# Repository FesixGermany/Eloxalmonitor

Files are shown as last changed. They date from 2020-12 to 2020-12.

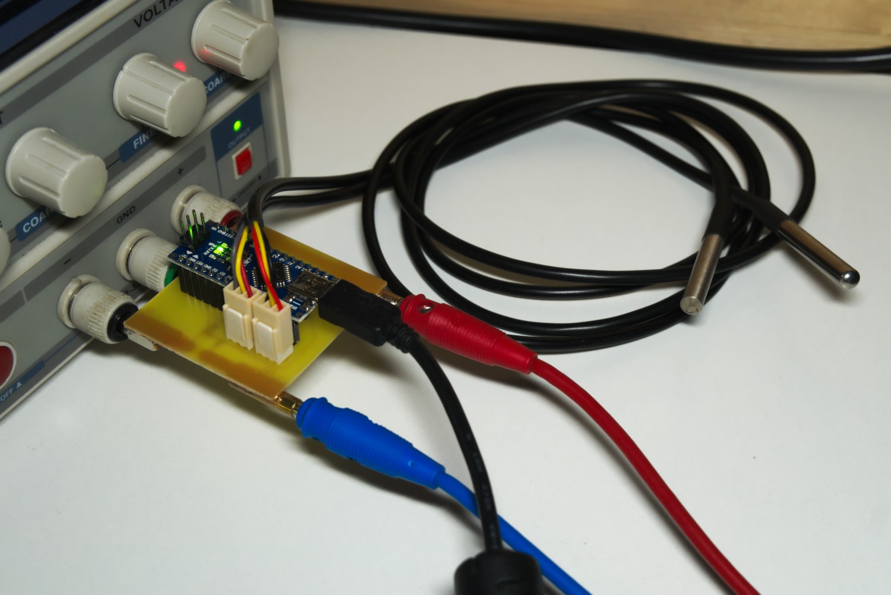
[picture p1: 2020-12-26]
documentation/overview.jpg

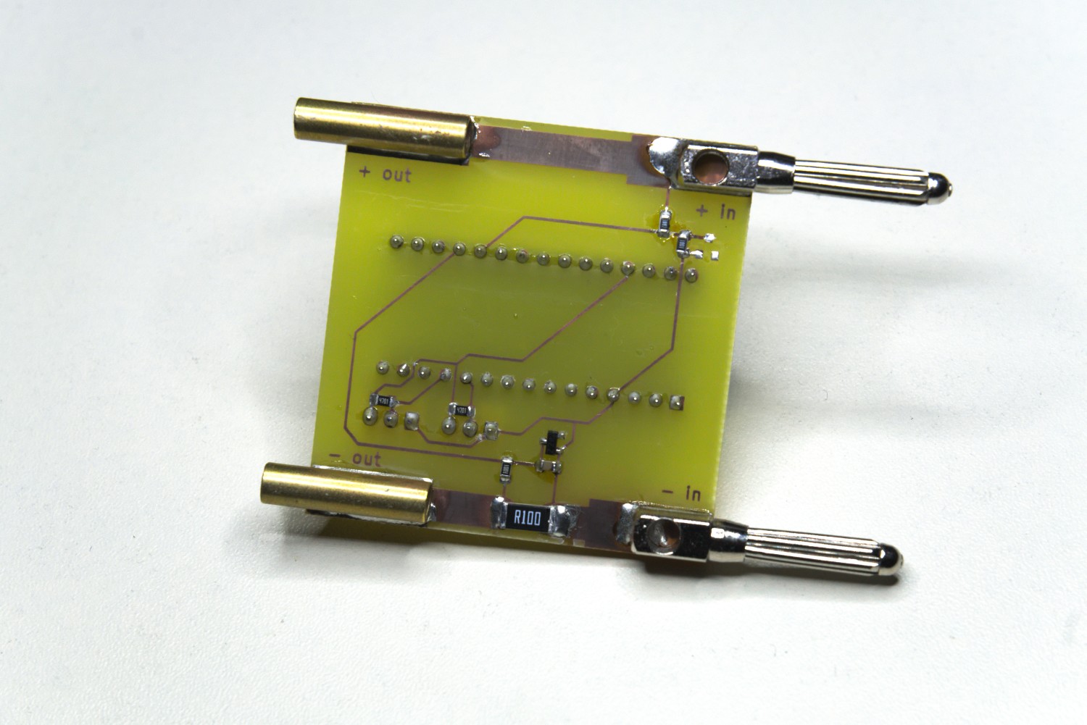
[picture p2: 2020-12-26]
documentation/PCB back.jpg

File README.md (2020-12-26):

# Eloxalmonitor  

This project started some years back when I started anodizing some aluminium at home.  
The temperature of the bath is very critical, when it gets too high the developed oxide pores start to destroy themselfes.  
That's why I wanted to read at least the temperature, voltage and current would be nice to know too.  

My friend Sven Mueller (who sadly passed away in 2018 just shy of 24 years old) wrote parts of the code, mainly the functions for onewire communication and decoding of the temperature back in 2017.  
I forgot about the project but now got into it again and finished it as good as I could by myself.  

## Circuit  

The brain is an Arduino Nano clone, convenient to use for serial communication with UART to USB converter on board.  
The main PCB plugs directly into my lab power supply, voltage gets read via voltage divider up to 30V DC, current is read via a 0R1 shunt resistor.  
Temperature of two basins can be read with two DS18B20 sensors who can be bought with cable attached and stainless steel cap.  

## Firmware 

The firmware for the ATmega 328P controller on the Nano is written in ATMEL Studio, not in Arduino IDE, therefore the controller was programmed with the .hex file which was compiled from ATMEL Studio via a AVR ISP programmer.
As far as I know it is possible to send the compiled .hex to an Arduino over USB with the bootloader installed and the program avrdude but didn't try that.  
**Important to note:** If compiling code yourself it is neccessary to add **libprintf_flt** to linker libraries and **use vprintf** library is set!

## Python GUI  

Script draws four graphs in realtime and stores them in a CSV file.  

Tested with/dependencies:  
python 2.7  
pyserial 3.5  
matplotlib 2.2.5  
numpy 1.16.0  

This is the first script I wrote in python, took some time to figure out how, I'm sure there are better ways but it works for me.

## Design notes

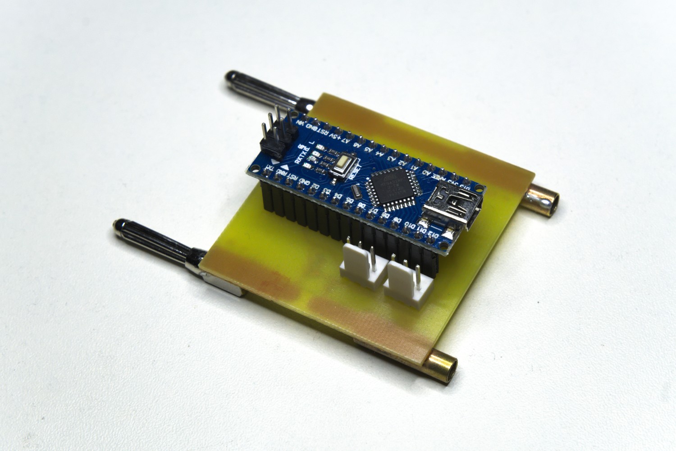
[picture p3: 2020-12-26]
documentation/PCB front.jpg

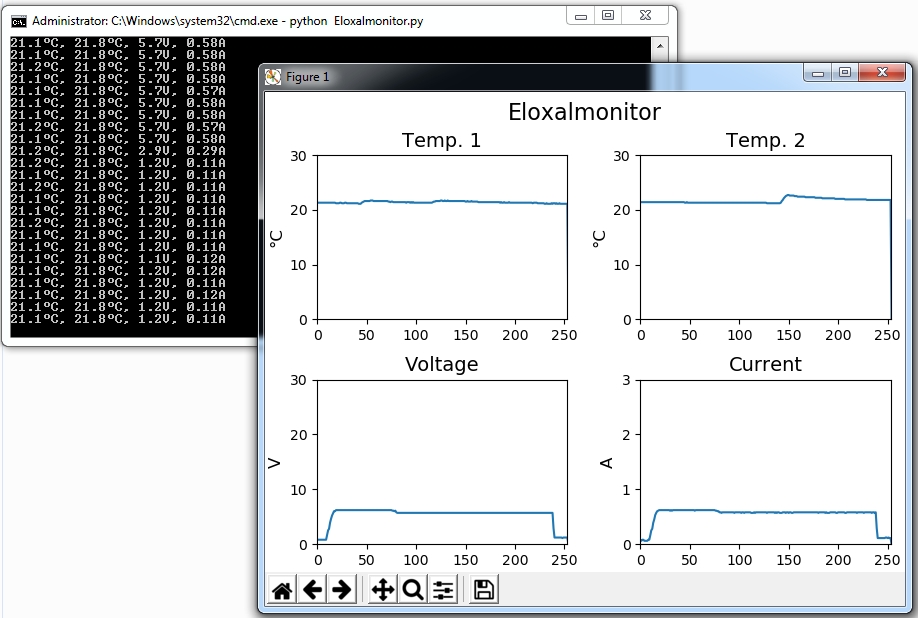
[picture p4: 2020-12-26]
documentation/python.jpg

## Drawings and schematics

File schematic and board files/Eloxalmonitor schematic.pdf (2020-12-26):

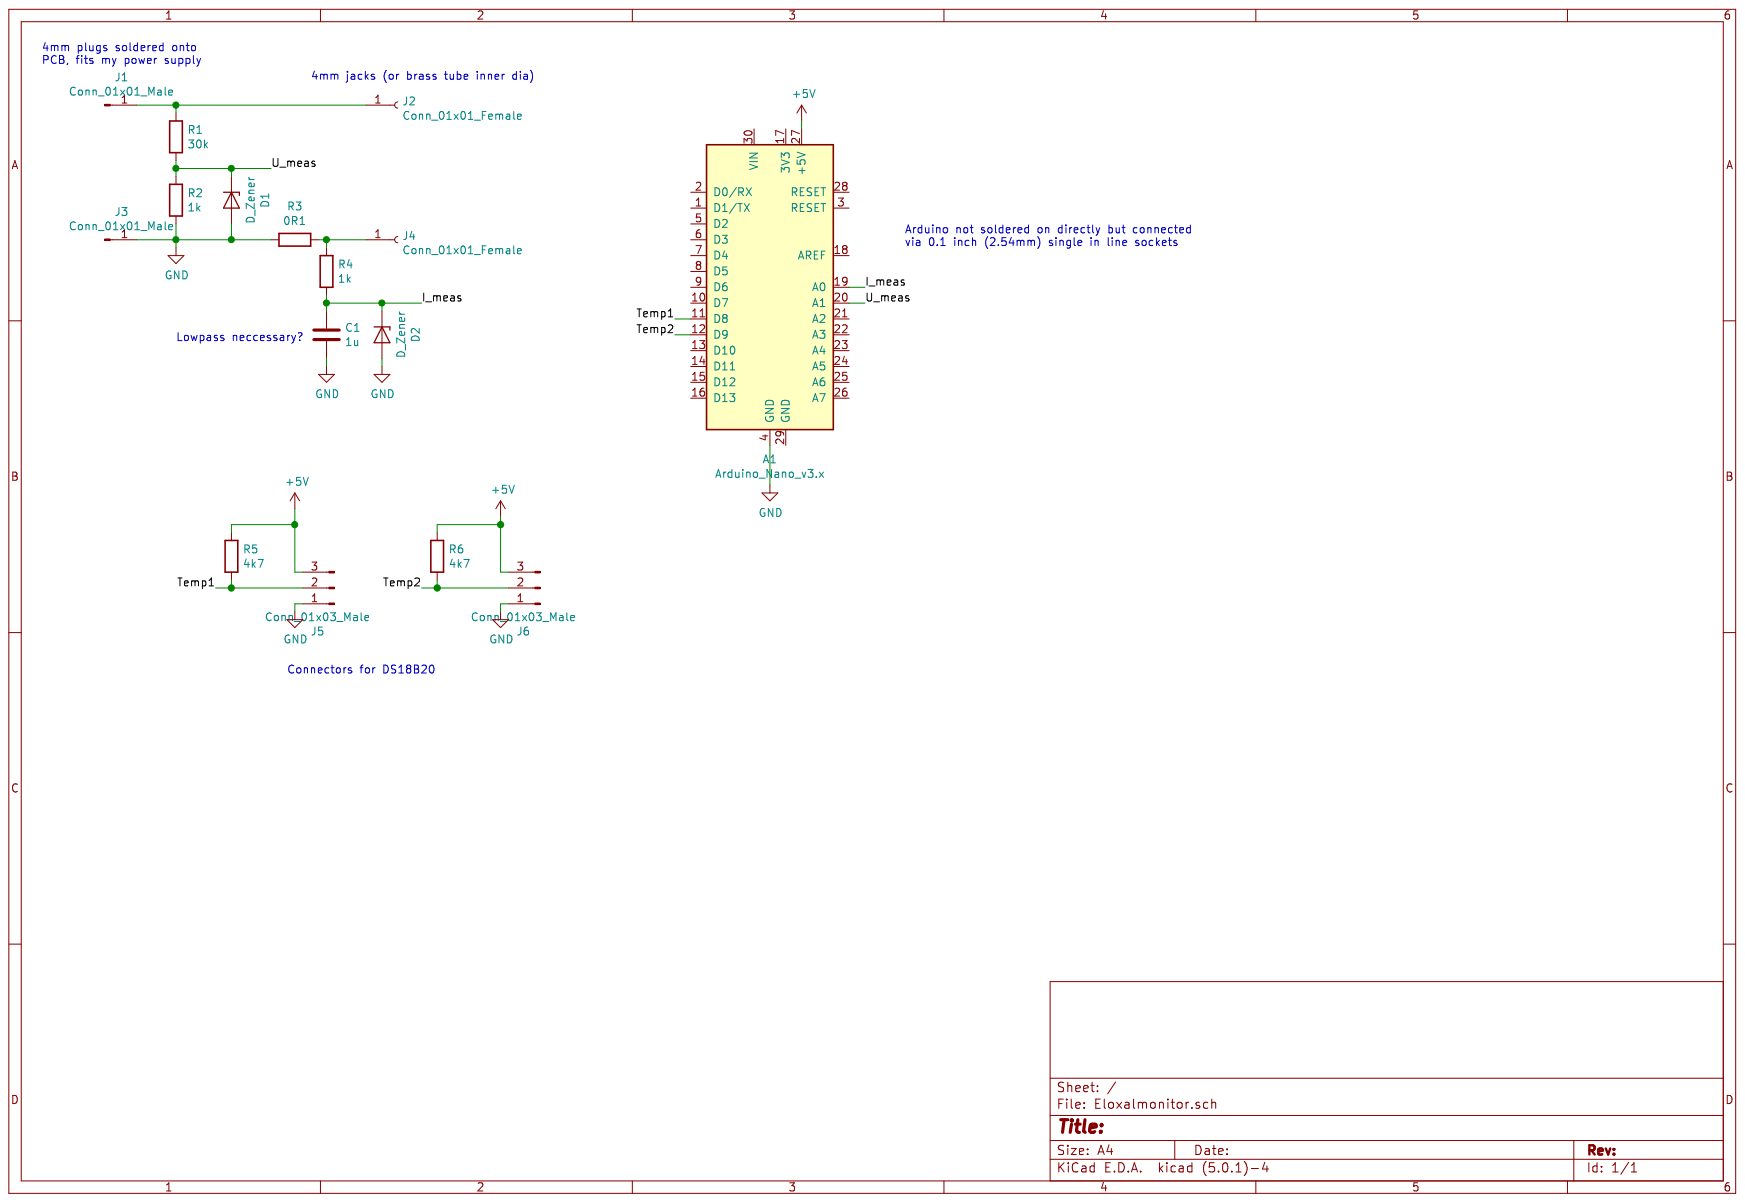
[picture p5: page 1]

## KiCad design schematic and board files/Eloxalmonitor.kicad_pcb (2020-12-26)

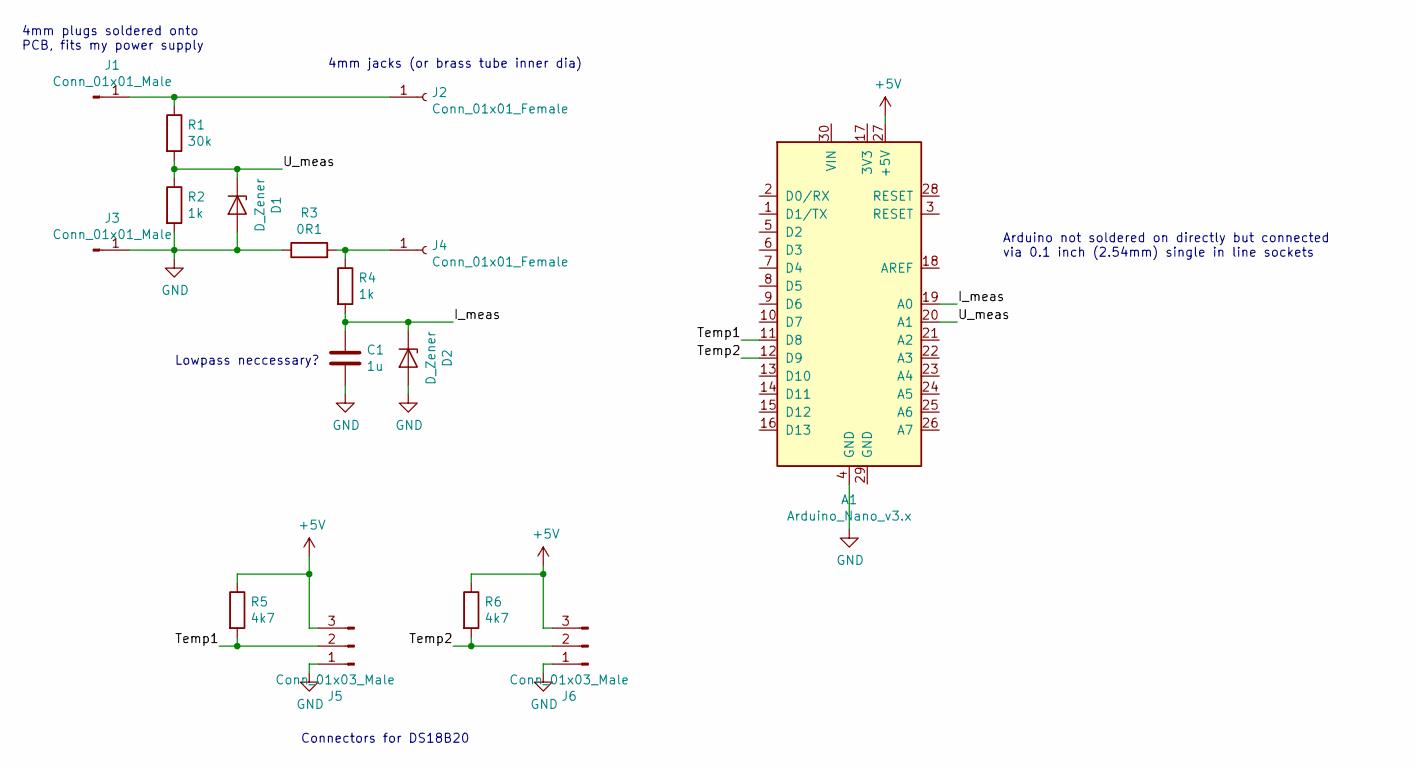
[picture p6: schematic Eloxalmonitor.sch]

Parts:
A1: Arduino_Nano_v3.x; Arduino_Nano
C1: 1u; C_0805_2012Metric_Pad1.15x1.40mm_HandSolder
D1, D2: D_Zener; D_SOT-23_ANK
J1, J3: Conn_01x01_Male; SolderWirePad_1x01_SMD_5x10mm
J2, J4: Conn_01x01_Female; SolderWirePad_1x01_SMD_5x10mm
J5, J6: Conn_01x03_Male; Molex_KK-254_AE-6410-03A_1x03_P2.54mm_Vertical
R1: 30k; R_0805_2012Metric_Pad1.15x1.40mm_HandSolder
R2, R4: 1k; R_0805_2012Metric_Pad1.15x1.40mm_HandSolder
R3: 0R1; R_2512_6332Metric_Pad1.52x3.35mm_HandSolder
R5, R6: 4k7; R_0805_2012Metric_Pad1.15x1.40mm_HandSolder

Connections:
+5V: A1.27 (+5V), J5.3, J6.3, R5.1, R6.1
/I_meas: A1.19 (A0), C1.1, D2.1 (K), R4.2
/Temp1: A1.11 (D8), J5.2, R5.2
/Temp2: A1.12 (D9), J6.2, R6.2
/U_meas: A1.20 (A1), D1.1 (K), R1.2, R2.1
GND: A1.4 (GND), C1.2, D1.2 (A), D2.2 (A), J3.1, J5.1, J6.1, R2.2, R3.1
unnamed: J1.1, J2.1, R1.1
unnamed: J4.1, R3.2, R4.1

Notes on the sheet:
Connectors for DS18B20
Lowpass neccessary?
Arduino not soldered on directly but connected via 0.1 inch (2.54mm) single in line sockets
4mm plugs soldered onto PCB, fits my power supply
4mm jacks (or brass tube inner dia)

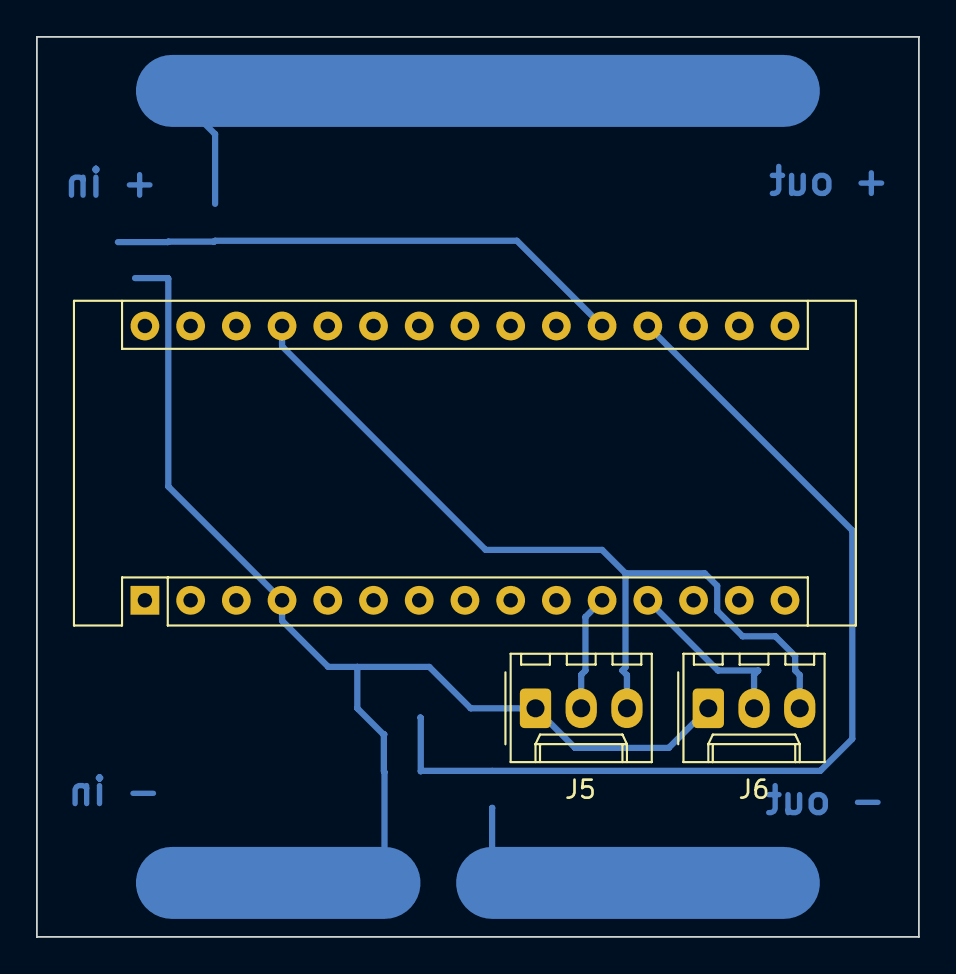
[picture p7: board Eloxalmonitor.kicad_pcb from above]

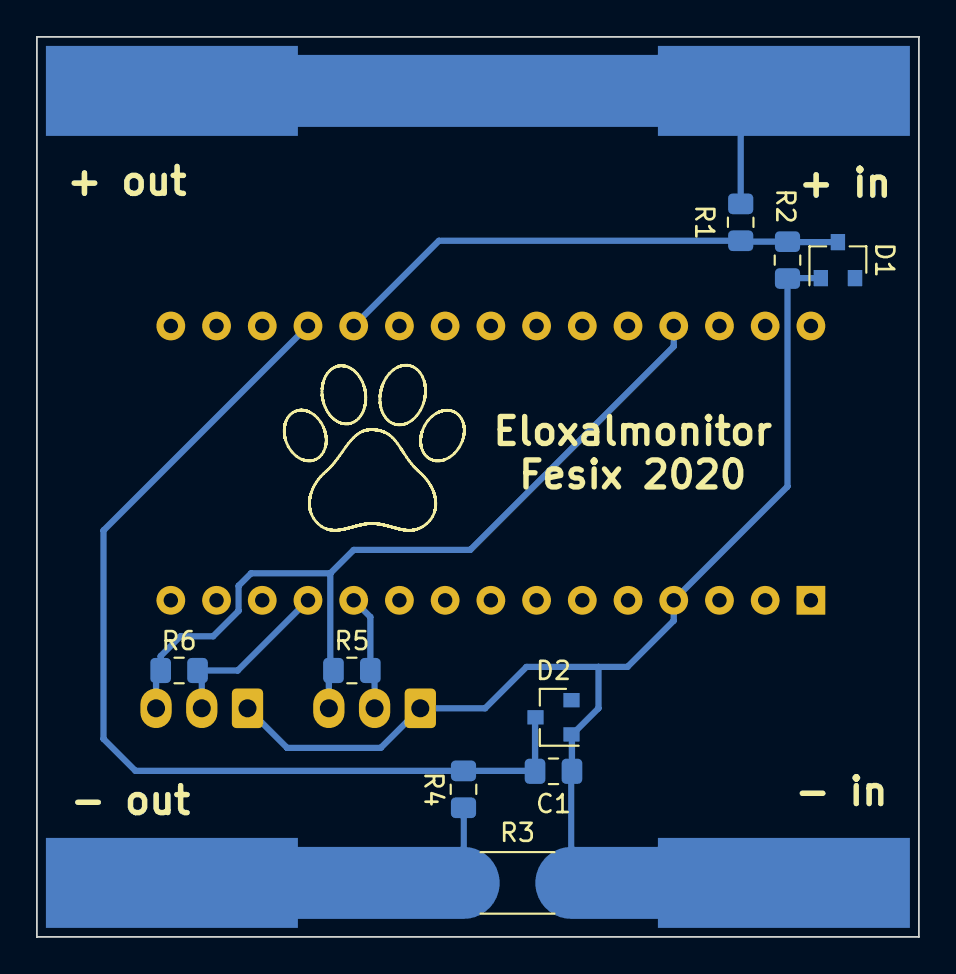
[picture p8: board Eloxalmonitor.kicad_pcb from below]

Board: 2 copper layers, 49.0 x 50.0 mm, 16 parts (13 on the bottom side), 8 nets.

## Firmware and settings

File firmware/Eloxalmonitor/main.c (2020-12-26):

/*
 * Project Eloxalmonitor
 *
 * Author: Fesix and Sven Mueller (RIP 2018 my dear friend)
 * Uses: ATmega 328P (Arduino Nano clone for convenience of board ready to use)
 *
 * Important: Only works if libprintf_flt is added to linker libraries and use vprintf library is set
 * 
 * Measures temperatures with DS18B20 onewire sensors, voltage and current for anodizing bath
 * Data gets sent over UART for further use (GUI, store as CSV, etc.)
 */ 

#include "main.h"

// Function for simultaneous conversion of temperature values, this takes some time
void MultiConvertT(uint8_t OWP1, uint8_t OWP2)
{
	uint8_t error = MultiOneWireReset(OWP1, OWP2);
	// Start conversion and wait until both lines read high (conversion finished)
	if((error & ((1 << OWP1) | (1 << OWP2))) == 0)
	{
		MultiOneWireSendCommand(CommandSkipROM, OWP1, OWP2);
		MultiOneWireSendCommand(CommandConvert, OWP1, OWP2);
		while((MultiReadBit(OWP1, OWP2) & ((1 << OWP1) | (1 << OWP2))) == 0)
			_delay_us(1);
	}
	// Start conversion only on line where reset was okay and wait until line reads high (conversion finished)
	else if (((error & (1 << OWP1)) == 0) && ((error & (1 << OWP2)) == 1))
	{
		OneWireSendCommand(CommandSkipROM, OWP1);
		OneWireSendCommand(CommandConvert, OWP1);
		while(!OneWireReadCommand(OWP1))
			_delay_us(1);
	}
	// Start conversion only on line where reset was okay and wait until line reads high (conversion finished)
	else if (((error & (1 << OWP2)) == 0) && ((error & (1 << OWP1)) == 1))
	{
		OneWireSendCommand(CommandSkipROM, OWP2);
		OneWireSendCommand(CommandConvert, OWP2);
		while(!OneWireReadCommand(OWP2))
			_delay_us(1);
	}
}

// Function for reading temperature data from one sensor and converting it into float
float ReadConvertDS18B20(uint8_t onewirepin)
{
	float value = 0.0;
	
	// Read scratchpad and format value
	if(!OneWireReset(onewirepin))									// If reset ok
	{
		uint16_t temp = 0;
		OneWireSendCommand(CommandSkipROM, onewirepin);				// Send SkipROM command
		OneWireSendCommand(CommandReadScratchPad, onewirepin);		// Send ReadScratchPad command
		temp = OneWireReadCommand(onewirepin);						// Read first byte
		temp |= OneWireReadCommand(onewirepin) << 8;				// Read second byte and put in from of first
		if((temp & 0xF800) > 0)										// If value is negative
		{
			temp = (~temp) + 1.0;									// Generate two's complement
			value = temp >> 4;										// Shift four bits to get rid of decimal places
			value += ((temp & 0x000F) * (1.0 / 16.0));				// Use bitmask for decimal places only, multiply by (1/16), because 8 Bit resolution
			value = value * -1.0;									// Multiplay by -1
		}
		else{
			value = temp >> 4;										// Shift four bits to get rid of decimal places
			value += ((temp & 0x000F) * (1.0 / 16.0));				// Use bitmask for decimal places only, multiply by (1/16), because 8 Bit resolution
		}
	}
	else
		value = 999.9;												// Return some crazy value as error message if reset was not okay
	
	return value;
}

uint8_t timer = 0;

int main(void)
{
	// Config Timer1 for 1s
	TCCR1B |= (1 << WGM12);						// CTC mode
	TCCR1B |= (1 << CS12) | (1 << CS10);		// Prescaler 1024
	OCR1A = 15624;								// Top value
	TIMSK1 |= (1 << OCIE1A);					// Timer1 A interrupt enable
	
	ADC_init();
	uinit();
	sei();
	
	// Main program loop
	while(1)
    {
		_delay_us(1);
		if(timer == 1)
		{
			char voltage[5];
			char current[5];
		
			// Read ADCs and do some calculation for voltage divider, compensate voltage drop across shunt
			float currentf = ADC_Read(0) * (0.001074 / ShuntValue) * CurrentCorrFactor;
			float voltagef = (((ADC_Read(1) * 0.001074) + (ADC_Read(1) * 0.001074 * VoltageDivider)) * VoltageCorrFactor) - (currentf * ShuntValue);

			char temp1[6];
			char temp2[6];
		
			// Start simultaneous conversion  of temperature, this takes some time
			MultiConvertT(OneWirePin1, OneWirePin2);
			// Read from sensors and convert into float
			float temp1f = ReadConvertDS18B20(OneWirePin1);
			float temp2f = ReadConvertDS18B20(OneWirePin2);
		
			// Convert float values for x amount of decimal places
			// Only works if libprintf_flt is added to linker libraries and use vprintf library is set
			sprintf(temp1, "%.1f", temp1f);	
			sprintf(temp2, "%.1f", temp2f);
			sprintf(current, "%.2f", currentf);
			sprintf(voltage, "%.1f", voltagef);
		
			// Send values over UART separated by semicolon
			uputs(temp1);
			uputs(";");
			uputs(temp2);
			uputs(";");
			uputs(voltage);
			uputs(";");
			uputsnl(current);
		
			timer = 0;
		}
    }
	return 1;
}

ISR (TIMER1_COMPA_vect)
{
	timer = 1;
}

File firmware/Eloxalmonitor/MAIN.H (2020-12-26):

#ifndef _main_h_
#define _main_h_

#define F_CPU 16000000UL

#define CurrentCorrFactor	1.0		// Correction factor for calculated and measured value
#define ShuntValue			0.1		// Value of current shunt in Ohm
#define VoltageDivider		30.0	// Ratio of resistors of voltage divider
#define VoltageCorrFactor	1.013	// Correction factor to compensate calculated and measured value

#include <avr/io.h>
#include <avr/interrupt.h>
#include <stdlib.h>
#include <stdio.h>
#include <stdbool.h>
#include <util/delay.h>

#include "ADC.h"

#define	BAUD		9600
#define bauddivider (unsigned int)(1.0 * F_CPU / BAUD / 16 - 1.0)
#include "uart.h"

#define OneWirePin1	PB0
#define OneWirePin2	PB1
#define OneWireOut	PORTB
#define OneWireIn	PINB
#define OneWireDDR	DDRB
#include "OneWire.h"

#define CommandSkipROM			0xCC
#define CommandReadROM			0x33
#define CommandSearchRom		0xF0
#define CommandConvert			0x44
#define CommandReadScratchPad	0xBE

#endif
